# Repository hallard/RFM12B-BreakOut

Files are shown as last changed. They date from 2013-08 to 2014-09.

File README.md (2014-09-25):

RFM12B RFM69CW breakout board NRF24L01 socket
=============================================

This is a utility breakout board for connecting RFM12B or RFM69CW device onto 
NRF24L01 sockets

this breakout add the feature of one of : 
- **adding** Micro SD card connector (V1.1 only)
- **adding** SPI Flash EEProm
- **adding** Some Leds to see what's going on

The 1.2 version has been added to be smaller than the 1.1 version, to achieve this I needed 
to remove the SD Card holder, so if you want SD use version 1.1.

1.2 version comes in two versions, one with classic 2x4 PTH connector and the other with the same
but SMD version of the connector, this permit to have the PCB quite the same size of the original
RFM12B or RFM69CM module size. Oh, also these boards are rounded instead of corners.

This has been created to work with the [ArduiPi][4] Project, but this breakout
can be used anywhere where you use NRF24L01 or has NRF24L01 connector.

The same breakout board exists also for RFM69W and RFM69HW on this [repo][2]
 
ArduiPi project is a shield for Raspberry Pi that brings Arduino low level extended I/O to Raspberry Pi.

You can find information about this project and others on [ArduiPi Site][4] 

Check out news and other on my [blog][5]

Detailed Description
====================

Everything is documented on this dedicated [post][6]

## **Version 1.2**  

### Schematic  
schematic  

### Boards  
board V1.2&nbsp;
top V1.2&nbsp;
bottom V1.2

## **Version 1.2 SMD connector**  

### Schematic  
schematic  
### Boards  
board V1.2 SMD&nbsp;
top V1.2 SMD&nbsp;
bottom V1.2 SMD

## **Version 1.1 with SD Card**  

### Schematic  
schematic  
### Boards  
board V1.1&nbsp;
top V1.1&nbsp;
bottom V1.1

[2]: [https://github.com/hallard/RFM69W-BreakOut]
[3]: http://hallard.me/rfm12b-breakout/ 
[4]: http://hallard.me/arduipi
[5]: http://hallard.me
[6]: http://hallard.me/rfm12b-breakout/

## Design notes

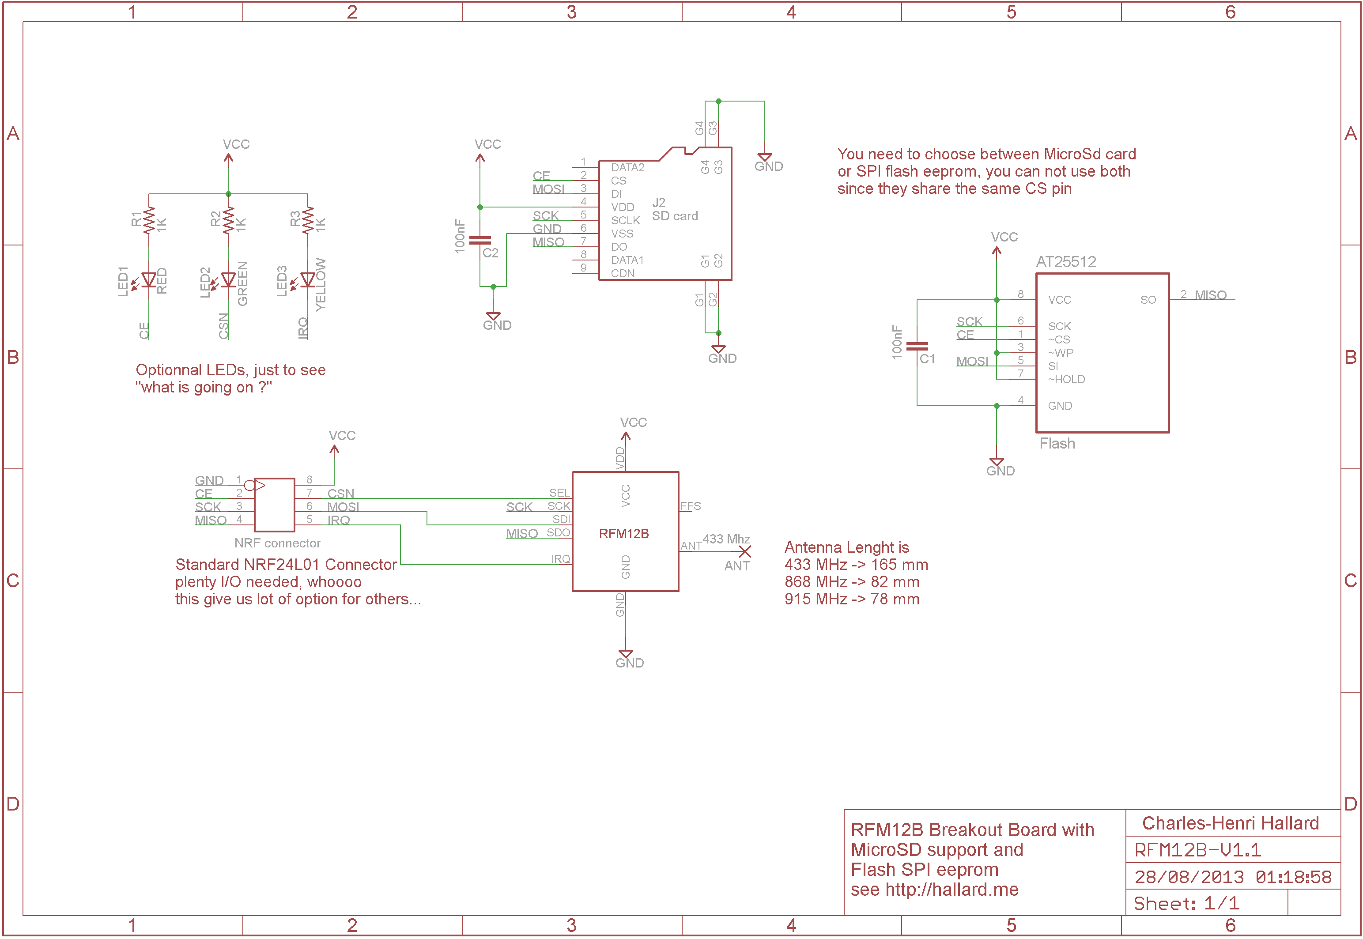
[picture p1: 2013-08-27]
RFM12B-V1.1-sch.png

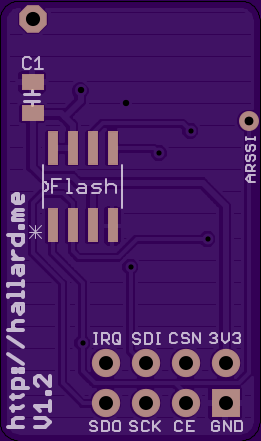
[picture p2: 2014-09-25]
RFM12B-V1.2-bottom.png

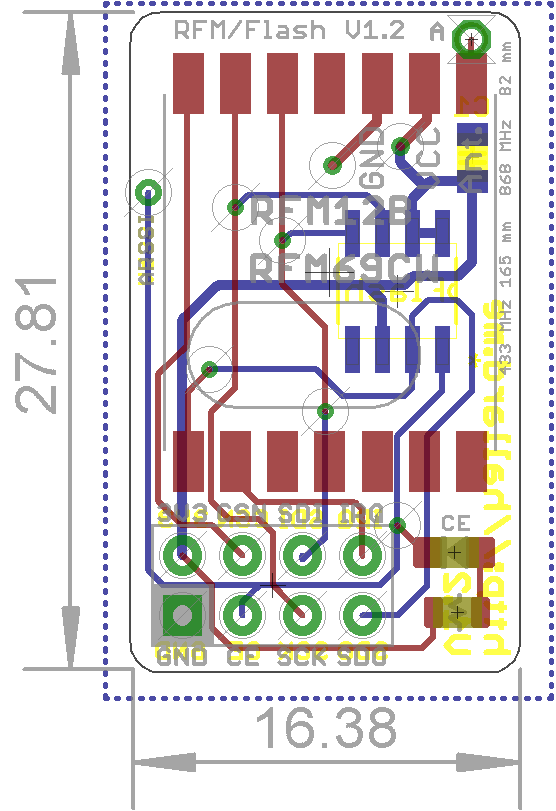
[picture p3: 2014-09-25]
RFM12B-V1.2-brd.png

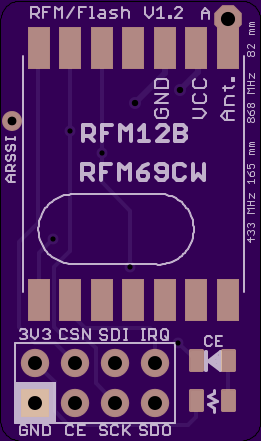
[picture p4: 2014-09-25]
RFM12B-V1.2-top.png

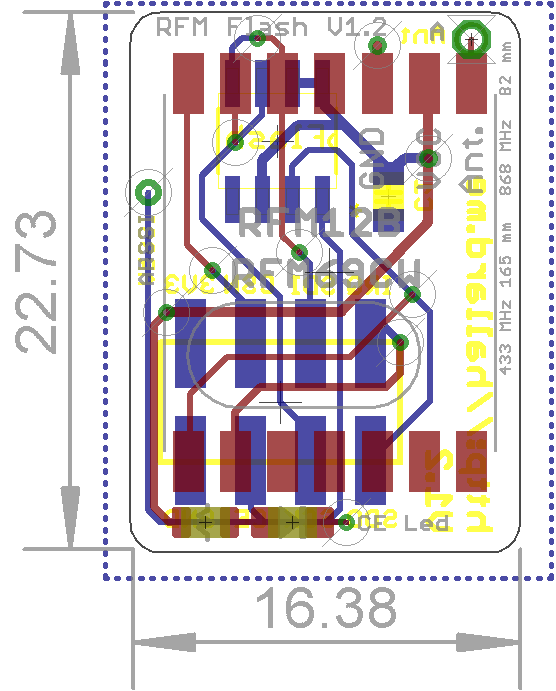
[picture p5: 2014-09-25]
RFM12B-V1.2-SMD-brd.png

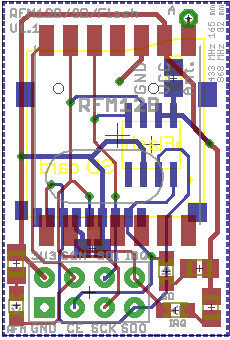
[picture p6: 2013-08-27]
RFM12B-V1.1-brd.png

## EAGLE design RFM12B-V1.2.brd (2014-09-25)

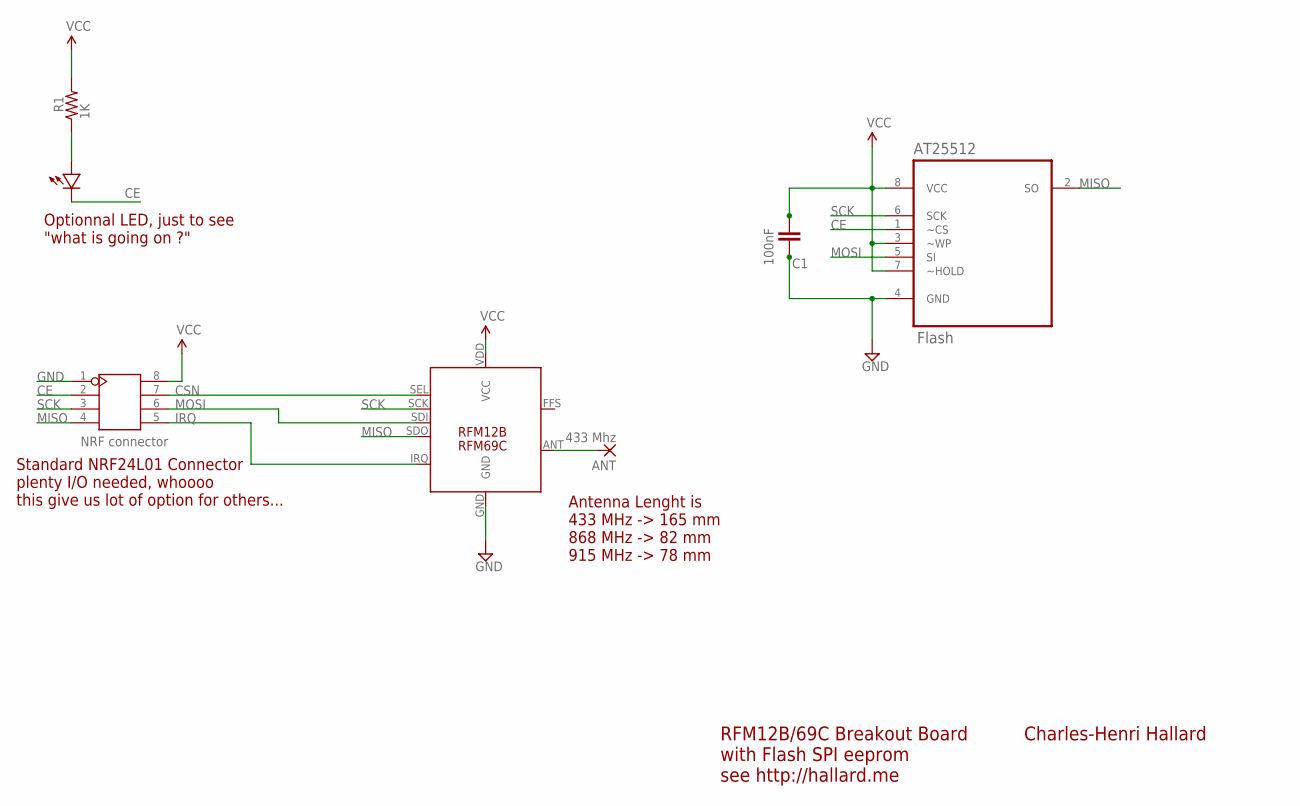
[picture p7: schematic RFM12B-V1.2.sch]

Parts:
ANT: 433 Mhz; 1,6/0,8
AT25512: Flash; SOIC127P600X175-8N
C1: 100nF; 0805-CAP
J1: NRF connector; 2X4P-2.54
R1: 1K; 0805-RES
U$1: LED0805-LARGE; 0805-LED-LARGEPADS
U$2: RFM12B

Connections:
CE: AT25512.1 (~CS), J1.2, U$1.MINUS
CSN: J1.7, U$2.SEL
GND: AT25512.4 (GND), C1.2, J1.1, U$2.GND
IRQ: J1.5, U$2.IRQ
MISO: AT25512.2 (SO), J1.4, U$2.SDO
MOSI: AT25512.5 (SI), J1.6, U$2.SDI
unnamed: ANT.1, U$2.ANT
unnamed: R1.1, U$1.PLUS
SCK: AT25512.6 (SCK), J1.3, U$2.SCK
VCC: AT25512.3 (~WP), AT25512.7 (~HOLD), AT25512.8 (VCC), C1.1, J1.8, R1.2, U$2.VDD (VCC)

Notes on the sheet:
RFM12B/69C Breakout Board with Flash SPI eeprom see http://hallard.me
Charles-Henri Hallard
Antenna Lenght is 433 MHz -> 165 mm 868 MHz -> 82 mm 915 MHz -> 78 mm
Optionnal LED, just to see "what is going on ?"
Standard NRF24L01 Connector plenty I/O needed, whoooo this give us lot of option for others...
RFM69C

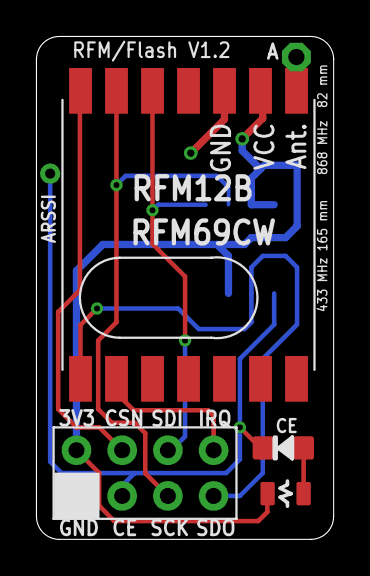
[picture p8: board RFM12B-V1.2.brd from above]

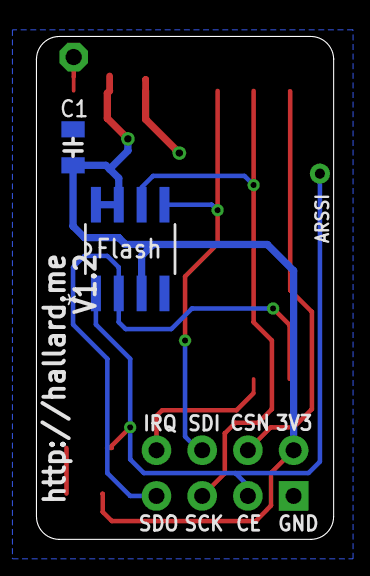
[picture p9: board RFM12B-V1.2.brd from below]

Board: 2 copper layers, 16.5 x 27.9 mm, 7 parts (2 on the bottom side), 10 nets.

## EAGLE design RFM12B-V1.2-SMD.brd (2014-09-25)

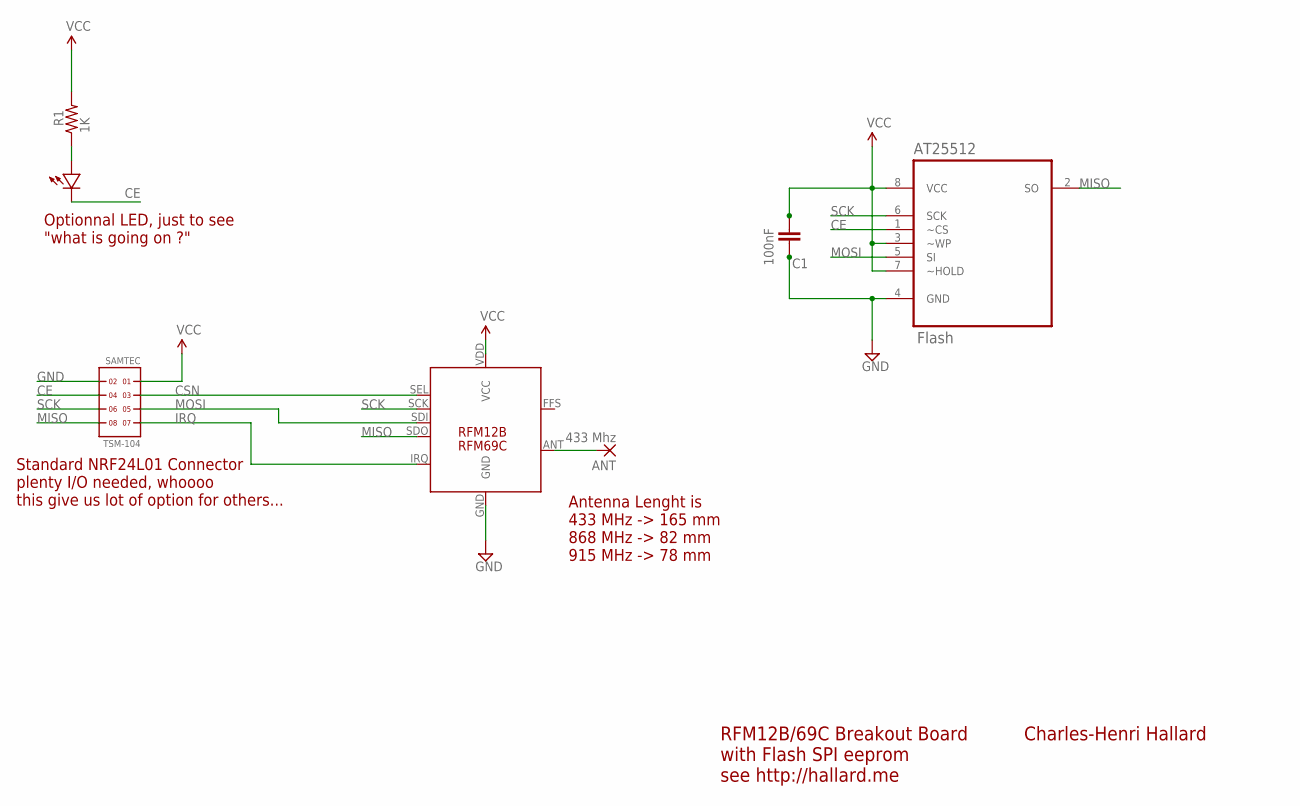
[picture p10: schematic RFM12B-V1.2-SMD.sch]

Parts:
ANT: 433 Mhz; 1,6/0,8
AT25512: Flash; SOIC127P600X175-8N
C1: 100nF; 0805-CAP
R1: 1K; 0805-RES
SAMTEC: TSM-104
U$2: RFM12B
U$3: LED0805-LARGE; 0805-LED-LARGEPADS

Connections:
CE: AT25512.1 (~CS), SAMTEC.4, U$3.MINUS
CSN: SAMTEC.3, U$2.SEL
GND: AT25512.4 (GND), C1.2, SAMTEC.2, U$2.GND
IRQ: SAMTEC.7, U$2.IRQ
MISO: AT25512.2 (SO), SAMTEC.8, U$2.SDO
MOSI: AT25512.5 (SI), SAMTEC.5, U$2.SDI
unnamed: ANT.1, U$2.ANT
unnamed: R1.1, U$3.PLUS
SCK: AT25512.6 (SCK), SAMTEC.6, U$2.SCK
VCC: AT25512.3 (~WP), AT25512.7 (~HOLD), AT25512.8 (VCC), C1.1, R1.2, SAMTEC.1, U$2.VDD (VCC)

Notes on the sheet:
RFM12B/69C Breakout Board with Flash SPI eeprom see http://hallard.me
Charles-Henri Hallard
Antenna Lenght is 433 MHz -> 165 mm 868 MHz -> 82 mm 915 MHz -> 78 mm
Optionnal LED, just to see "what is going on ?"
Standard NRF24L01 Connector plenty I/O needed, whoooo this give us lot of option for others...
RFM69C

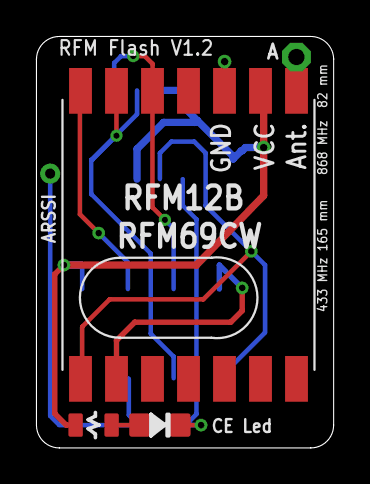
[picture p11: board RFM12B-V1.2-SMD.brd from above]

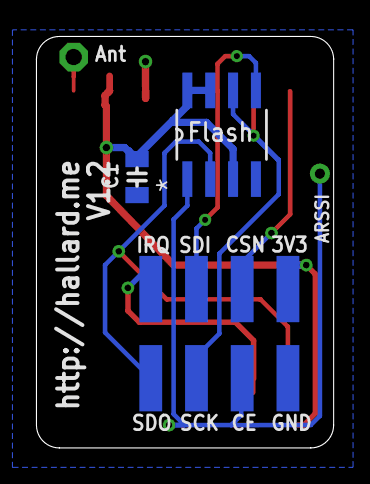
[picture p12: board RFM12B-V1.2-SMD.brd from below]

Board: 2 copper layers, 16.5 x 22.9 mm, 7 parts (3 on the bottom side), 10 nets.

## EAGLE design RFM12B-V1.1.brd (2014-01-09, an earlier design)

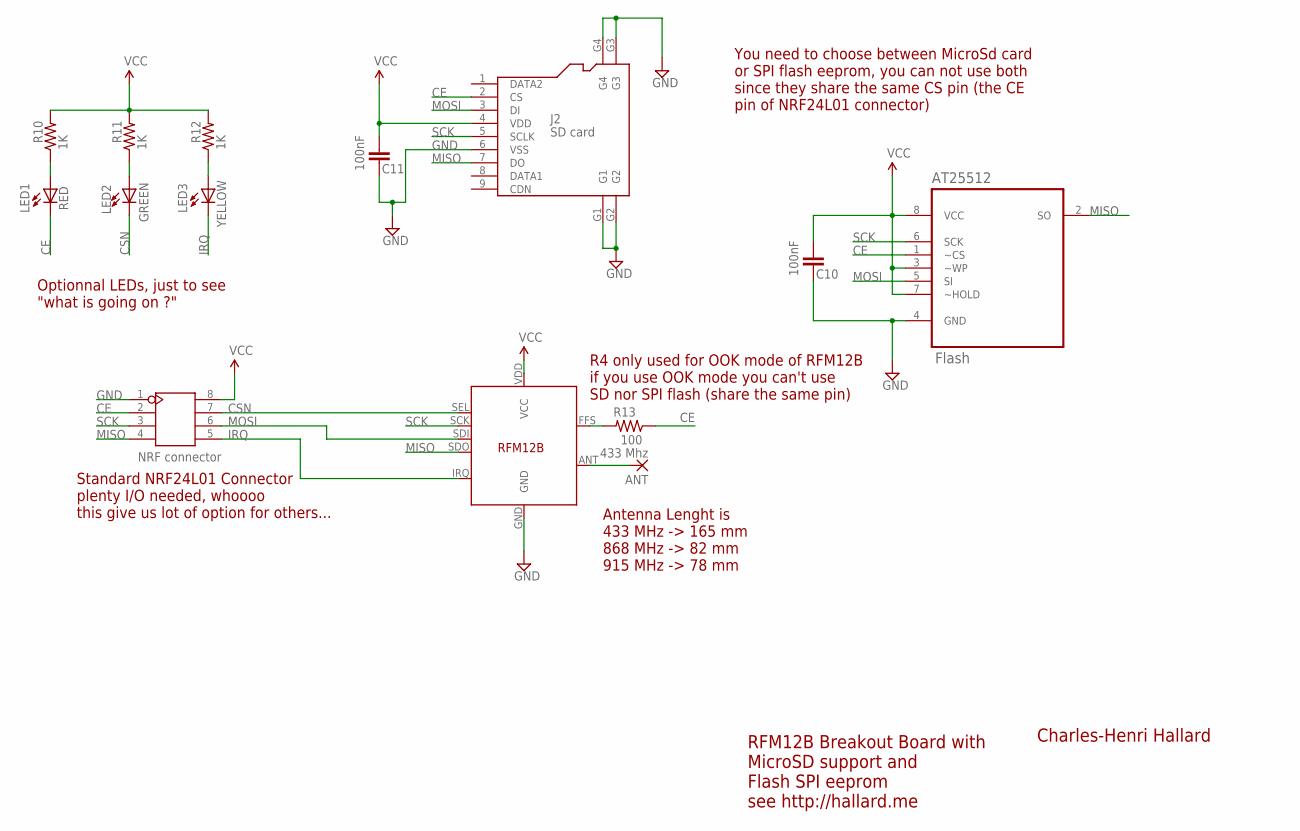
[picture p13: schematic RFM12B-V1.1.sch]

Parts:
ANT: 433 Mhz; 1,6/0,8
AT25512: Flash; SOIC127P600X175-8N
C10, C11: 100nF; C0805
J1: NRF connector; 2X4P-2.54
J2: SD card; 9P-SMD-W/-RING
LED1: RED; LED-805
LED2: GREEN; LED-805
LED3: YELLOW; LED-805
R10, R11, R12: 1K; M0805
R13: 100; M0805
U$2: RFM12B

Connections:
CE: AT25512.1 (~CS), J1.2, J2.2 (CS), LED1.C, R13.1
CSN: J1.7, LED2.C, U$2.SEL
GND: AT25512.4 (GND), C10.2, C11.2, J1.1, J2.6 (VSS), J2.G1, J2.G2, J2.G3, J2.G4, U$2.GND
IRQ: J1.5, LED3.C, U$2.IRQ
MISO: AT25512.2 (SO), J1.4, J2.7 (DO), U$2.SDO
MOSI: AT25512.5 (SI), J1.6, J2.3 (DI), U$2.SDI
unnamed: ANT.1, U$2.ANT
unnamed: LED1.A, R10.1
unnamed: LED2.A, R11.1
unnamed: LED3.A, R12.1
unnamed: R13.2, U$2.FFS
SCK: AT25512.6 (SCK), J1.3, J2.5 (SCLK), U$2.SCK
VCC: AT25512.3 (~WP), AT25512.7 (~HOLD), AT25512.8 (VCC), C10.1, C11.1, J1.8, J2.4 (VDD), R10.2, R11.2, R12.2, U$2.VDD (VCC)

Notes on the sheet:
RFM12B Breakout Board with MicroSD support and Flash SPI eeprom see http://hallard.me
Charles-Henri Hallard
Antenna Lenght is 433 MHz -> 165 mm 868 MHz -> 82 mm 915 MHz -> 78 mm
You need to choose between MicroSd card or SPI flash eeprom, you can not use both since they share the same CS pin (the CE pin of NRF24L01 connector)
Optionnal LEDs, just to see "what is going on ?"
Standard NRF24L01 Connector plenty I/O needed, whoooo this give us lot of option for others...
R4 only used for OOK mode of RFM12B if you use OOK mode you can't use SD nor SPI flash (share the same pin)

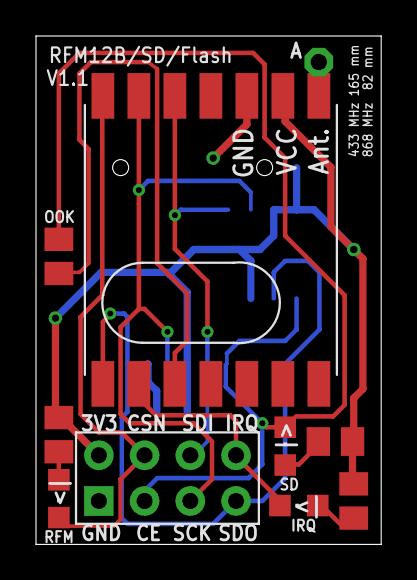
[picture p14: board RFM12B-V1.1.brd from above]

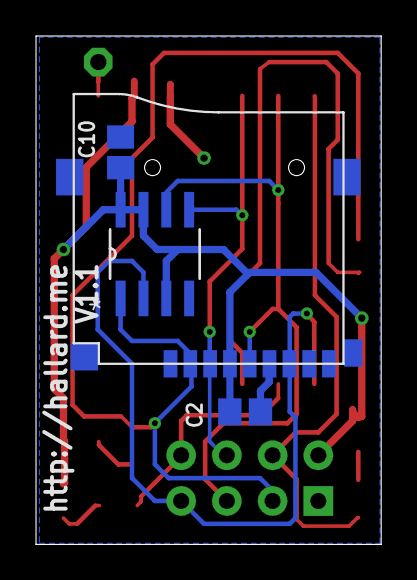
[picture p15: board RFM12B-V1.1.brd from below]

Board: 2 copper layers, 19.2 x 28.2 mm, 14 parts (4 on the bottom side), 13 nets.

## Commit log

2013-08-27 Initial Commit
    Initial Commit
    [RFM12B-V1.1.brd, RFM12B-V1.1.sch]
2014-01-09 Version sent to OSH
    Latest revision sent to PCB fab
    [RFM12B-V1.1.brd, RFM12B-V1.1.sch]
2014-09-25 Added version 1.2 and 1.2 SMD
    Added smaller version 1.2 and ultra small 1.2 SMD
    [RFM12B-V1.2-SMD.brd, RFM12B-V1.2-SMD.sch, RFM12B-V1.2.brd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]
